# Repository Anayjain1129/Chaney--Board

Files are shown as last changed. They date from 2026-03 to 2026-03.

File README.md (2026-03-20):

# Chaney-Board
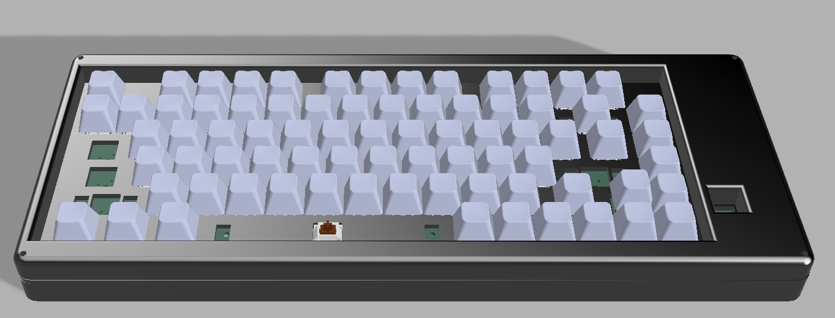
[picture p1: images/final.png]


Features:

- Rotary Encoder for volume control
- 81x keys
- Raspberry Pi Pico
- Customised layout
- QMK firmware
  
### Schematic
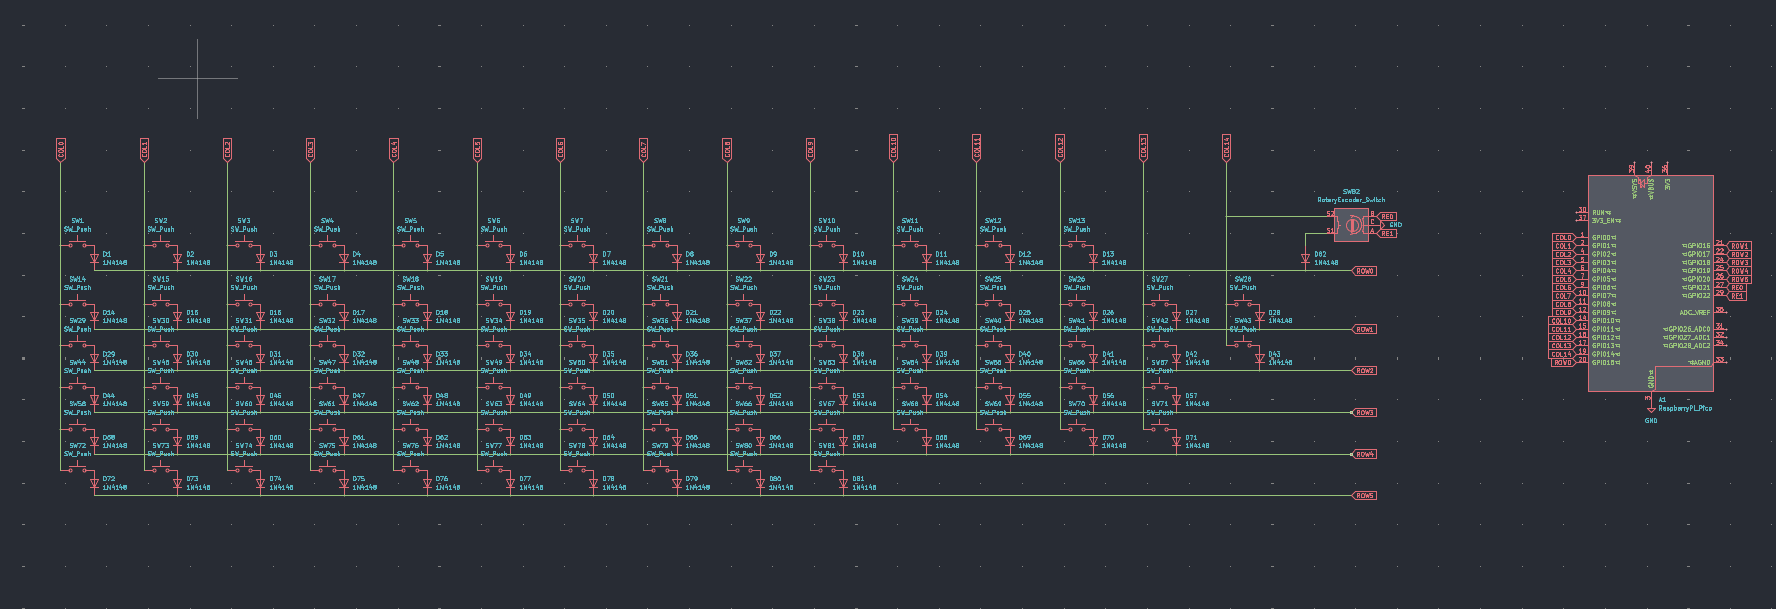
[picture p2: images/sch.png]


### PCB 
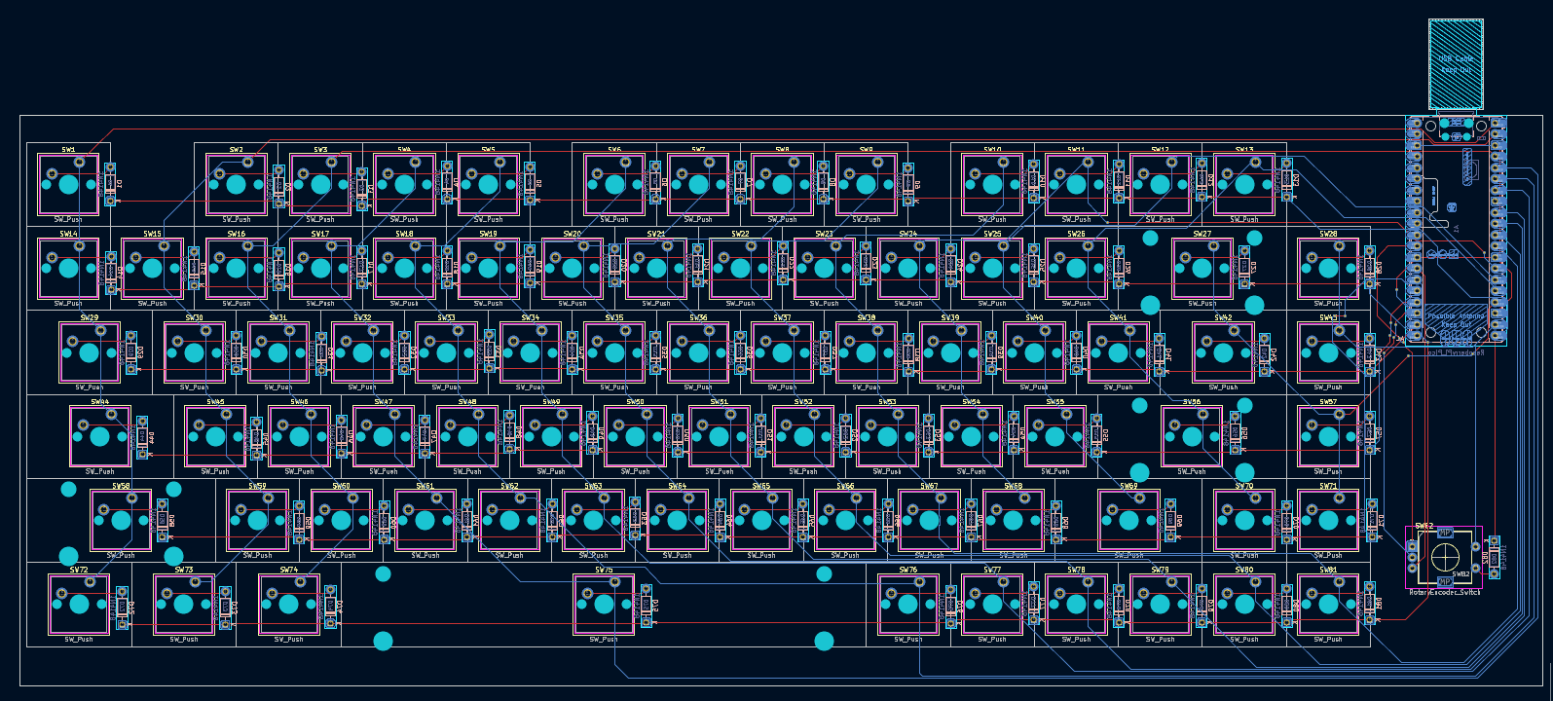
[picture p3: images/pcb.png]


### Case
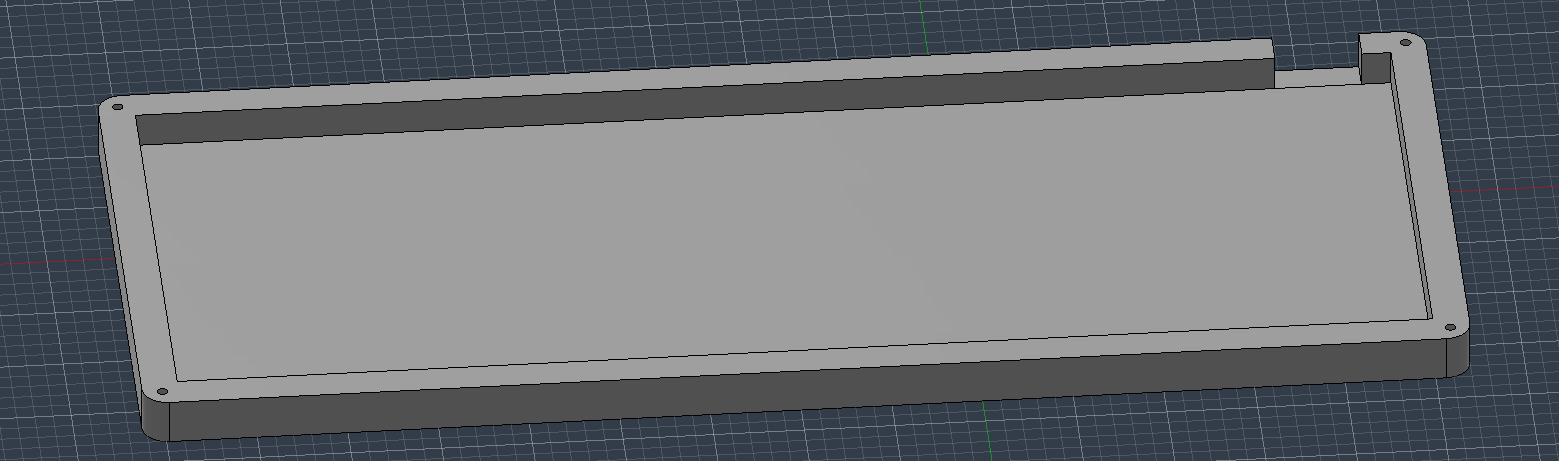
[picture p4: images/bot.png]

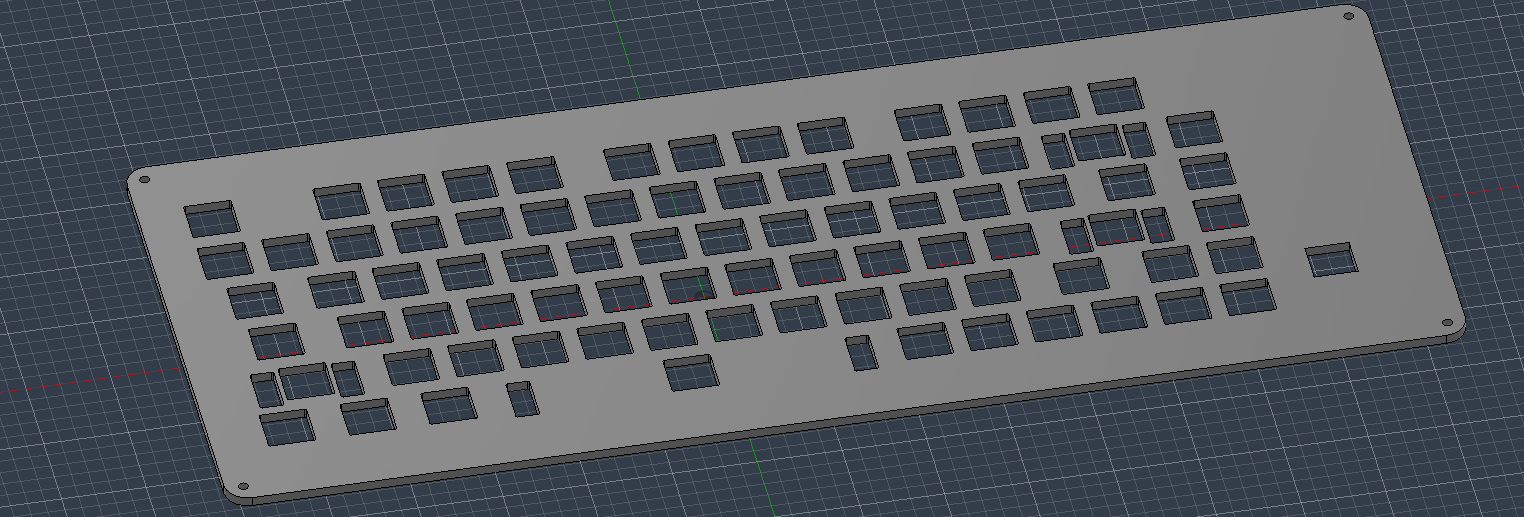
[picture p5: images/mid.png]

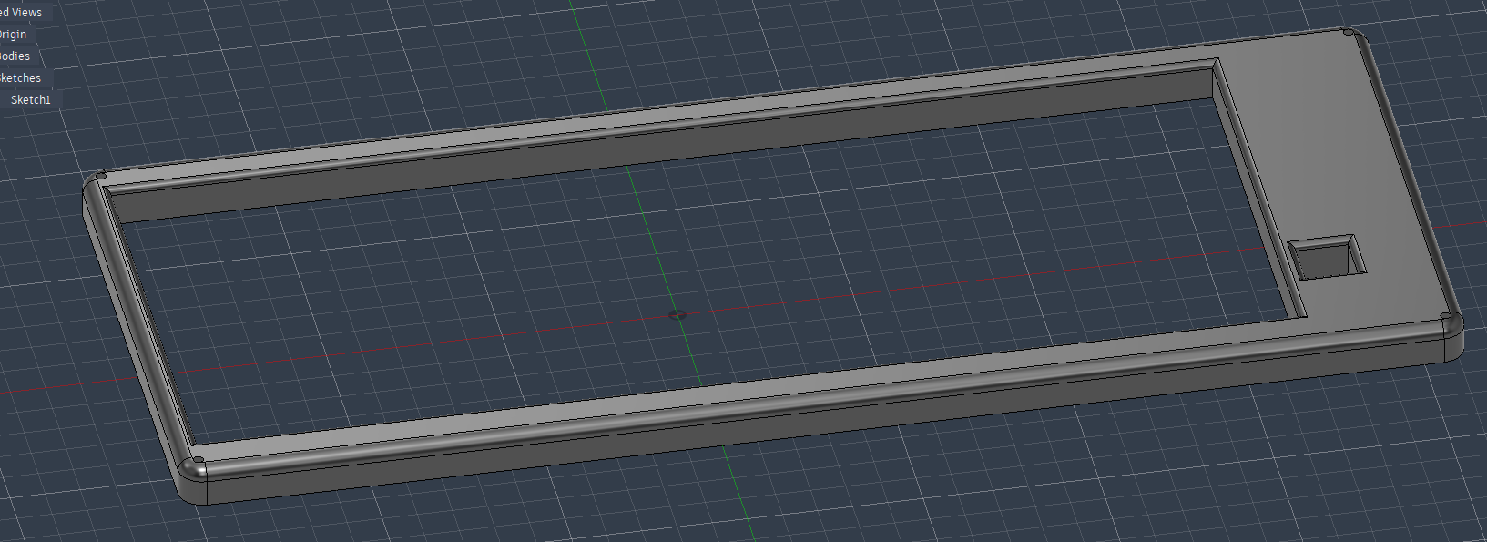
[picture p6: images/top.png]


### 3D view of all parts together 


### BOM


| Name | Quantity | Cost | Link |
|---|---|---|---|
| TTC Silent Red V3 | 81 | $45.11 | [Buy](https://stackskb.com/store/ttc-silent-red-v3-switch/) |
| Durock Smokey Screw-In Stabilizers V2 (4+1 w/ 6.25u spacebar) | 1 | $17.01 | [Buy](https://stackskb.com/store/durock-smokey-screw-in-stabilizers-v2/) |
| EC11 Rotary Encoder with Switch | 1 | $0.68 | [Buy](https://www.flyrobo.in/15mm-ec11-rotary-encoder-with-switch-digital-potentiometer) |
| Mount Fuji Premium Moa Profile PBT Keycap | 1 | $28.78 | [Buy](https://curiositycaps.in/products/fugaju-premium-moa-profile-pbt-keycap?_pos=21&_sid=c0043ab41&_ss=r) |
| Diode 1N4148 Through-Hole | 100 | $1.06 | [Buy](https://www.amazon.in/dp/B084ZP5BJ3) |
| PCB - (Black Color) | 5 | $60.00 | [Buy](https://jlcpcb.com/) |
| Raspberry Pi Pico | 1 | $6.40 | [Buy](https://www.amazon.in/Raspberry-Pi-Headers-Soldered-Micro/dp/B08WPNM7JB) |
| Heatset and Screws | 1 | $0.00 | Self-sourced |
| Case (top, mid, bot) | 1 | $0.00 | Printing Legion |
| **Total** | | **$158.99** | |

The total costs comes out to be $159

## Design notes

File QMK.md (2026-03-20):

## Flashing & Configuring the Keyboard

Steps to install the firmware and configure the keyboard:-

### 1. Download the .uf2 file from repo
Download it and save it on your computer locally

### 2. Enter Boot Mode on the Pico
1. Unplug the Raspberry Pi Pico from your computer.
2. Hold down the **BOOTSEL** button on the Pico.
3. While holding the button, plug the Pico into your computer using a USB cable.
4. The computer will detect a new drive, namely **RPI-RP2**.

### 3. Flash the Firmware
1. Download the `.uf2` firmware file from this repo.
2. Drag and drop the file onto the **RPI-RP2** drive.

Once the file finishes copying, the Pico will reboot automatically.

### 5. Configure the Keymap
The keyboard layout can be customised in the .json file and keymap.c

Open the file in a text editor and edit the keymap section to match the layout.  
After saving the file, the keyboard will automatically reload with the new configuration.

### 6. Test the Keyboard
Unplug and reconnect the keyboard, open a text editor, and press some keys to make sure everything works.

and then we havee yeyyeyeiaieiieie enjoye!!!

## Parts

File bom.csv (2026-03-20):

Name | Quantity | Cost | Link
TTC Silent Red V3 | 81 | $45.11 | https://stackskb.com/store/ttc-silent-red-v3-switch/
Durock Smokey Screw-In Stabilizers V2 (4+1 w/ 6.25u spacebar) | 1 | $17.01 | https://stackskb.com/store/durock-smokey-screw-in-stabilizers-v2/
EC11 Rotary Encoder with Switch | 1 | $0.68 | https://www.flyrobo.in/15mm-ec11-rotary-encoder-with-switch-digital-potentiometer
Mount Fuji Premium Moa Profile PBT Keycap | 1 | $28.78 | https://curiositycaps.in/products/fugaju-premium-moa-profile-pbt-keycap?_pos=21&_sid=c0043ab41&_ss=r
Diode 1N4148 Through - Hole | 100 | $1.06 | https://www.amazon.in/dp/B084ZP5BJ3?ref_=cm_sw_r_cp_ud_dp_YPW3WFYTE31QA18570D1&_encoding=UTF8&psc=1
PCB - (Black Color) | 5 | $60 | https://jlcpcb.com/
Raspberry Pi Pico | 1 | $6.4 | https://www.amazon.in/Raspberry-Pi-Headers-Soldered-Micro/dp/B08WPNM7JB/ref=sr_1_3?sr=8-3
Heatset and Screws | 1 | $0 | Self-sourced
Case- top,mid,bot | 1 | $0.00 | Printing Legion

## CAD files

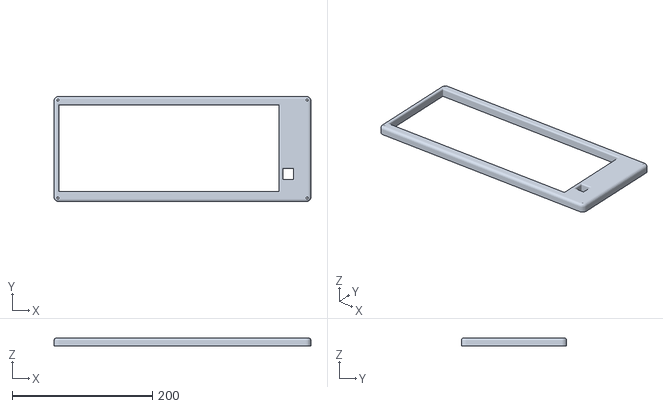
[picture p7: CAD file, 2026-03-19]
CAD/top.stl
366.2 x 150.2 x 12.0

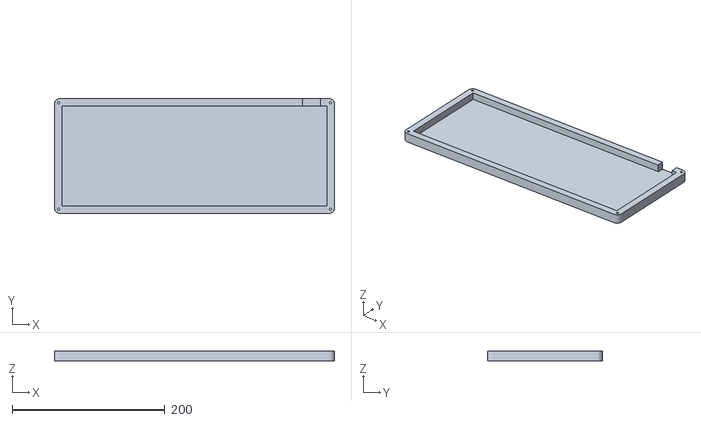
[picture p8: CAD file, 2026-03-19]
CAD/bottom.stl
366.2 x 150.2 x 13.0

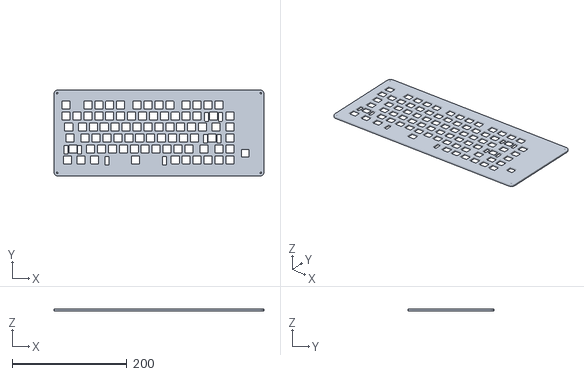
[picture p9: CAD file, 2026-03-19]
CAD/middle.stl
366.2 x 150.2 x 3.00

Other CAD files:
CAD source Files/bottom.f3d
CAD source Files/middle.f3d
CAD source Files/top.f3d

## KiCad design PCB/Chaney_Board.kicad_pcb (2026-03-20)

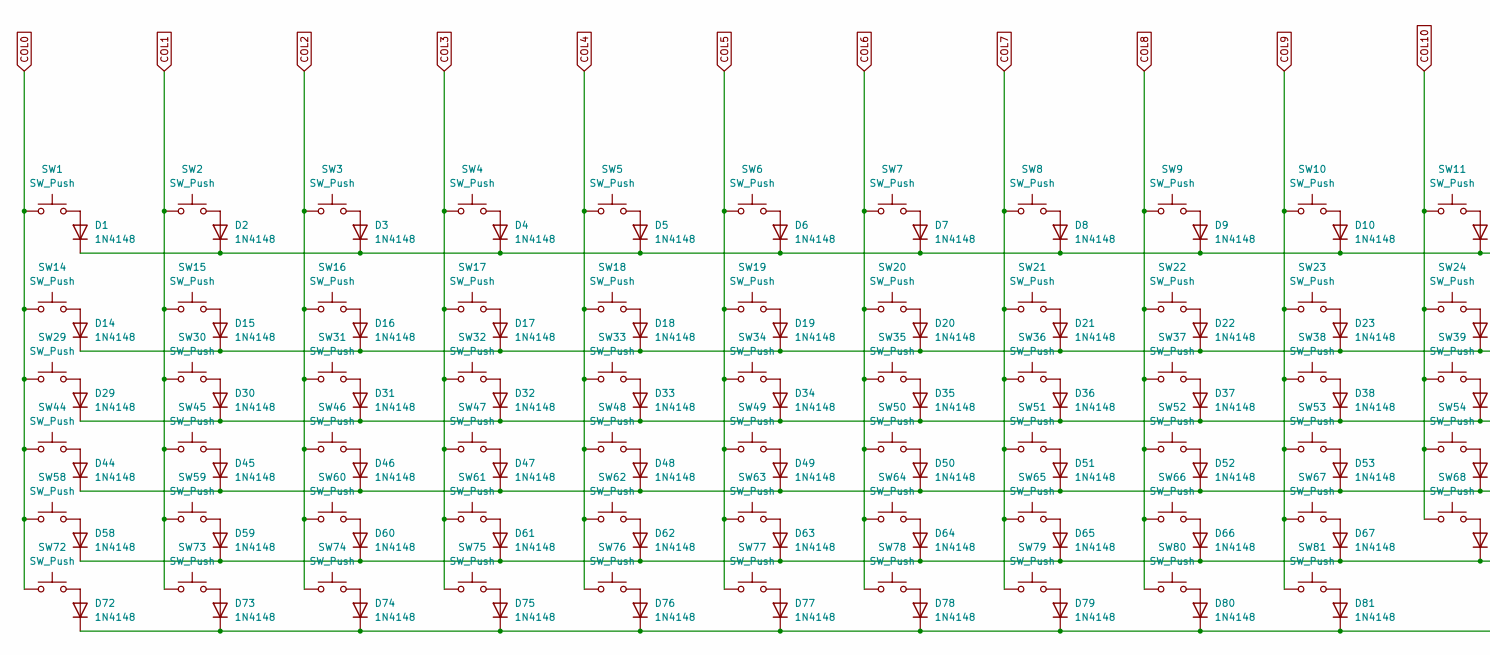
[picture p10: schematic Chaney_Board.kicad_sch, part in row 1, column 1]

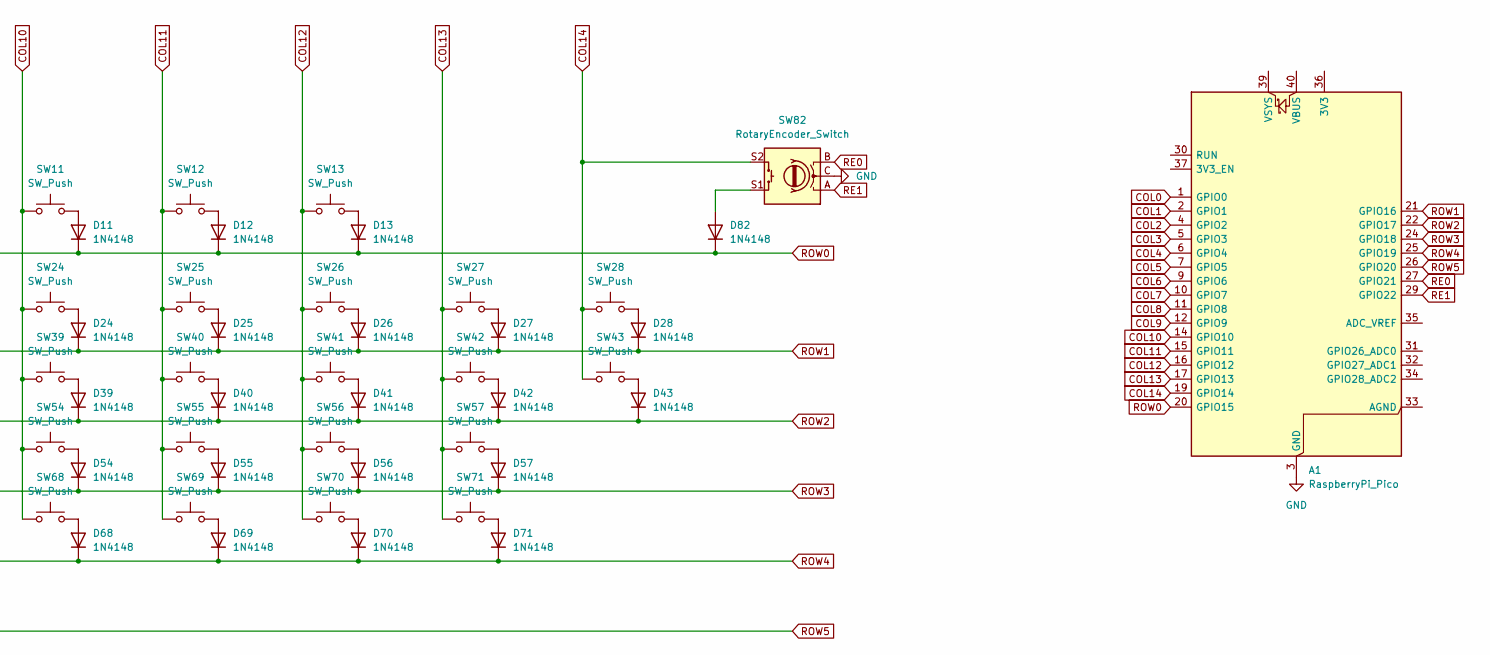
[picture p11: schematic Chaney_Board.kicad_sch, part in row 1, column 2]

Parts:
A1: RaspberryPi_Pico; RaspberryPi_Pico_Common_Unspecified
D1, D2, D3, D4, D5, D6, D7, D8, D9, D10, D11, D12, D13, D14, D15, D16, D17, D18, D19, D20, D21, D22, D23, D24, D25, D26, D27, D28, D29, D30, D31, D32, D33, D34, D35, D36, D37, D38, D39, D40, D41, D42, D43, D44, D45, D46, D47, D48, D49, D50, D51, D52, D53, D54, D55, D56, D57, D58, D59, D60, D61, D62, D63, D64, D65, D66, D67, D68, D69, D70, D71, D72, D73, D74, D75, D76, D77, D78, D79, D80, D81, D82: 1N4148; D_DO-35_SOD27_P7.62mm_Horizontal
SW1, SW2, SW3, SW4, SW5, SW6, SW7, SW8, SW9, SW10, SW11, SW12, SW13, SW14, SW15, SW16, SW17, SW18, SW19, SW20, SW21, SW22, SW23, SW24, SW25, SW26, SW28, SW30, SW31, SW32, SW33, SW34, SW35, SW36, SW37, SW38, SW39, SW40, SW41, SW43, SW45, SW46, SW47, SW48, SW49, SW50, SW51, SW52, SW53, SW54, SW55, SW57, SW59, SW60, SW61, SW62, SW63, SW64, SW65, SW66, SW67, SW68, SW70, SW71, SW76, SW77, SW78, SW79, SW80, SW81: SW_Push; SW_Cherry_MX_1.00u_PCB
SW27: SW_Push; SW_Cherry_MX_2.00u_PCB
SW29, SW42: SW_Push; SW_Cherry_MX_1.50u_PCB
SW44, SW69: SW_Push; SW_Cherry_MX_1.75u_PCB
SW56, SW58: SW_Push; SW_Cherry_MX_2.25u_PCB
SW72, SW73, SW74: SW_Push; SW_Cherry_MX_1.25u_PCB
SW75: SW_Push; SW_Cherry_MX_6.25u_PCB
SW82: RotaryEncoder_Switch; RotaryEncoder_Alps_EC11E-Switch_Vertical_H20mm

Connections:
COL0: A1.1 (GPIO0), SW1.1, SW14.1, SW29.1, SW44.1, SW58.1, SW72.1
COL1: A1.2 (GPIO1), SW2.1, SW15.1, SW30.1, SW45.1, SW59.1, SW73.1
COL2: A1.4 (GPIO2), SW3.1, SW16.1, SW31.1, SW46.1, SW60.1, SW74.1
COL3: A1.5 (GPIO3), SW4.1, SW17.1, SW32.1, SW47.1, SW61.1, SW75.1
COL4: A1.6 (GPIO4), SW5.1, SW18.1, SW33.1, SW48.1, SW62.1, SW76.1
COL5: A1.7 (GPIO5), SW6.1, SW19.1, SW34.1, SW49.1, SW63.1, SW77.1
COL6: A1.9 (GPIO6), SW7.1, SW20.1, SW35.1, SW50.1, SW64.1, SW78.1
COL7: A1.10 (GPIO7), SW8.1, SW21.1, SW36.1, SW51.1, SW65.1, SW79.1
COL8: A1.11 (GPIO8), SW9.1, SW22.1, SW37.1, SW52.1, SW66.1, SW80.1
COL9: A1.12 (GPIO9), SW10.1, SW23.1, SW38.1, SW53.1, SW67.1, SW81.1
COL10: A1.14 (GPIO10), SW11.1, SW24.1, SW39.1, SW54.1, SW68.1
COL11: A1.15 (GPIO11), SW12.1, SW25.1, SW40.1, SW55.1, SW69.1
COL12: A1.16 (GPIO12), SW13.1, SW26.1, SW41.1, SW56.1, SW70.1
COL13: A1.17 (GPIO13), SW27.1, SW42.1, SW57.1, SW71.1
COL14: A1.19 (GPIO14), SW28.1, SW43.1, SW82.S2
GND: A1.3 (GND), A1.8 (GND), A1.13 (GND), A1.18 (GND), A1.23 (GND), A1.28 (GND), A1.38 (GND), SW82.C
unnamed: D1.2 (A), SW1.2
unnamed: D2.2 (A), SW2.2
unnamed: D3.2 (A), SW3.2
unnamed: D4.2 (A), SW4.2
unnamed: D5.2 (A), SW5.2
unnamed: D6.2 (A), SW6.2
unnamed: D7.2 (A), SW7.2
unnamed: D8.2 (A), SW8.2
unnamed: D9.2 (A), SW9.2
unnamed: D10.2 (A), SW10.2
unnamed: D11.2 (A), SW11.2
unnamed: D12.2 (A), SW12.2
unnamed: D13.2 (A), SW13.2
unnamed: D14.2 (A), SW14.2
unnamed: D15.2 (A), SW15.2
unnamed: D16.2 (A), SW16.2
unnamed: D17.2 (A), SW17.2
unnamed: D18.2 (A), SW18.2
unnamed: D19.2 (A), SW19.2
unnamed: D20.2 (A), SW20.2
unnamed: D21.2 (A), SW21.2
unnamed: D22.2 (A), SW22.2
unnamed: D23.2 (A), SW23.2
unnamed: D24.2 (A), SW24.2
unnamed: D25.2 (A), SW25.2
unnamed: D26.2 (A), SW26.2
unnamed: D27.2 (A), SW27.2
unnamed: D28.2 (A), SW28.2
unnamed: D29.2 (A), SW29.2
unnamed: D30.2 (A), SW30.2
unnamed: D31.2 (A), SW31.2
unnamed: D32.2 (A), SW32.2
unnamed: D33.2 (A), SW33.2
unnamed: D34.2 (A), SW34.2
unnamed: D35.2 (A), SW35.2
unnamed: D36.2 (A), SW36.2
unnamed: D37.2 (A), SW37.2
unnamed: D38.2 (A), SW38.2
unnamed: D39.2 (A), SW39.2
unnamed: D40.2 (A), SW40.2
unnamed: D41.2 (A), SW41.2
unnamed: D42.2 (A), SW42.2
unnamed: D43.2 (A), SW43.2
unnamed: D44.2 (A), SW44.2
unnamed: D45.2 (A), SW45.2
unnamed: D46.2 (A), SW46.2
unnamed: D47.2 (A), SW47.2
unnamed: D48.2 (A), SW48.2
unnamed: D49.2 (A), SW49.2
unnamed: D50.2 (A), SW50.2
unnamed: D51.2 (A), SW51.2
unnamed: D52.2 (A), SW52.2
unnamed: D53.2 (A), SW53.2
unnamed: D54.2 (A), SW54.2
unnamed: D55.2 (A), SW55.2
unnamed: D56.2 (A), SW56.2
unnamed: D57.2 (A), SW57.2
unnamed: D58.2 (A), SW58.2
unnamed: D59.2 (A), SW59.2
unnamed: D60.2 (A), SW60.2
unnamed: D61.2 (A), SW61.2
unnamed: D62.2 (A), SW62.2
unnamed: D63.2 (A), SW63.2
unnamed: D64.2 (A), SW64.2
unnamed: D65.2 (A), SW65.2
unnamed: D66.2 (A), SW66.2
unnamed: D67.2 (A), SW67.2
unnamed: D68.2 (A), SW68.2
unnamed: D69.2 (A), SW69.2
unnamed: D70.2 (A), SW70.2
unnamed: D71.2 (A), SW71.2
unnamed: D72.2 (A), SW72.2
unnamed: D73.2 (A), SW73.2
unnamed: D74.2 (A), SW74.2
unnamed: D75.2 (A), SW75.2
unnamed: D76.2 (A), SW76.2
unnamed: D77.2 (A), SW77.2
unnamed: D78.2 (A), SW78.2
unnamed: D79.2 (A), SW79.2
unnamed: D80.2 (A), SW80.2
unnamed: D81.2 (A), SW81.2
unnamed: D82.2 (A), SW82.S1
RE0: A1.27 (GPIO21), SW82.B
RE1: A1.29 (GPIO22), SW82.A
ROW0: A1.20 (GPIO15), D1.1 (K), D2.1 (K), D3.1 (K), D4.1 (K), D5.1 (K), D6.1 (K), D7.1 (K), D8.1 (K), D9.1 (K), D10.1 (K), D11.1 (K), D12.1 (K), D13.1 (K), D82.1 (K)
ROW1: A1.21 (GPIO16), D14.1 (K), D15.1 (K), D16.1 (K), D17.1 (K), D18.1 (K), D19.1 (K), D20.1 (K), D21.1 (K), D22.1 (K), D23.1 (K), D24.1 (K), D25.1 (K), D26.1 (K), D27.1 (K), D28.1 (K)
ROW2: A1.22 (GPIO17), D29.1 (K), D30.1 (K), D31.1 (K), D32.1 (K), D33.1 (K), D34.1 (K), D35.1 (K), D36.1 (K), D37.1 (K), D38.1 (K), D39.1 (K), D40.1 (K), D41.1 (K), D42.1 (K), D43.1 (K)
ROW3: A1.24 (GPIO18), D44.1 (K), D45.1 (K), D46.1 (K), D47.1 (K), D48.1 (K), D49.1 (K), D50.1 (K), D51.1 (K), D52.1 (K), D53.1 (K), D54.1 (K), D55.1 (K), D56.1 (K), D57.1 (K)
ROW4: A1.25 (GPIO19), D58.1 (K), D59.1 (K), D60.1 (K), D61.1 (K), D62.1 (K), D63.1 (K), D64.1 (K), D65.1 (K), D66.1 (K), D67.1 (K), D68.1 (K), D69.1 (K), D70.1 (K), D71.1 (K)
ROW5: A1.26 (GPIO20), D72.1 (K), D73.1 (K), D74.1 (K), D75.1 (K), D76.1 (K), D77.1 (K), D78.1 (K), D79.1 (K), D80.1 (K), D81.1 (K)

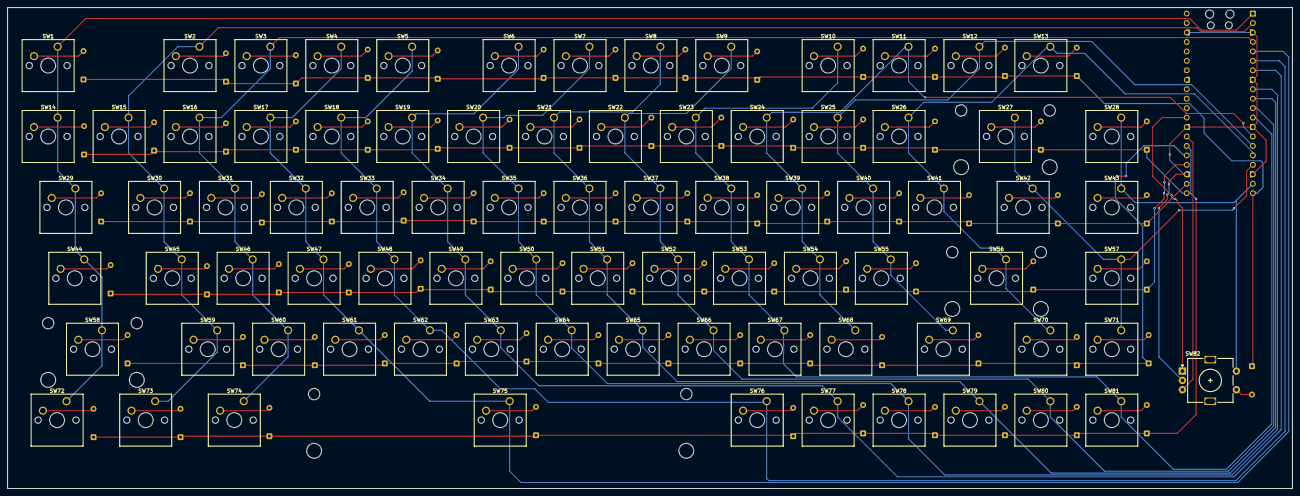
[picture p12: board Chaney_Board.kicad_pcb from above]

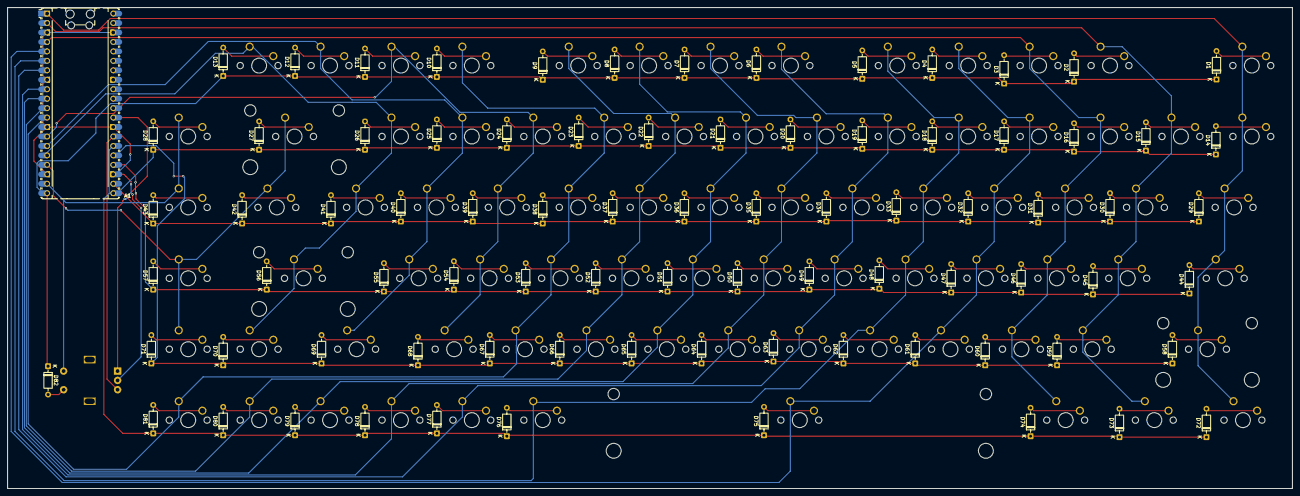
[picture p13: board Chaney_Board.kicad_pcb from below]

Board: 2 copper layers, 345.2 x 129.2 mm, 165 parts (83 on the bottom side), 106 nets.

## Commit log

2026-03-19 added lots of files
    [Chaney_Board.kicad_pcb, Chaney_Board.kicad_sch, bottom.stl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]
2026-03-19 updaetd bom
2026-03-19 added BOM
    [bom.csv]
2026-03-19 uhhh updated to right switches
2026-03-19 updated to right switches
    [BOM.csv]
2026-03-19 Fix formatting for Key switches entry in BOM.csv
    [BOM.csv]
2026-03-20 Update README with BOM section and formatting
    Added BOM section to README and formatted content.
2026-03-20 Update bom.csv with new keycap and link changes
    Replaced old keycap entry with a new Mount Fuji keycap entry and updated Raspberry Pi Pico link.
    [bom.csv]
2026-03-20 Update README.md with project details
    Restored and formatted the README content for Chaney-Board.
2026-03-20 Revise README with BOM and updated cost details
    Updated the README to include a detailed BOM with costs and links for components.
